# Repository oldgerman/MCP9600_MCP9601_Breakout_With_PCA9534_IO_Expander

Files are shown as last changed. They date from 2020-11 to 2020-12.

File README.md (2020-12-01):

# MCP9600/MCP9601 Breakout, With PCA9534 IO Expander 

- <span style="color:rgb(255, 0, 0);">The module has a bug, don’t make a board.</span>
- <span style="color:rgb(255, 0, 0);">该模块有BUG，不要打板</span>

## PCB

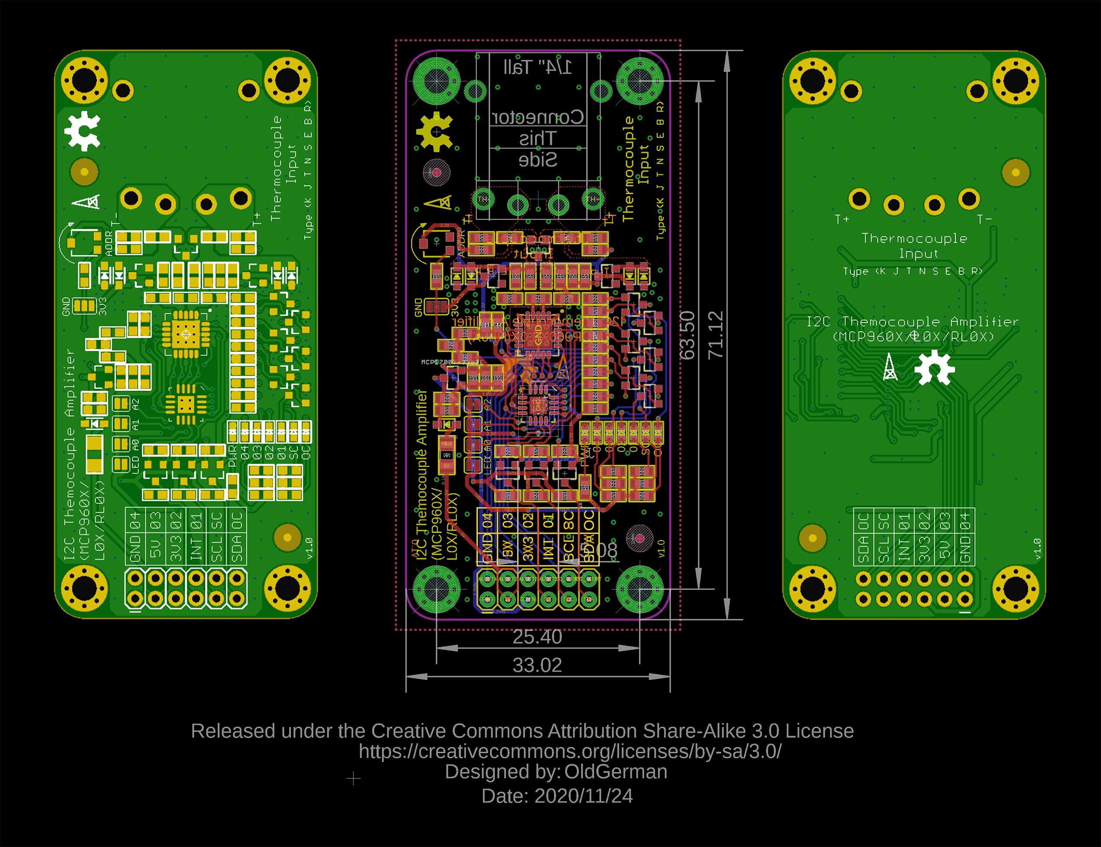
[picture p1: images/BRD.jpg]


## SCH

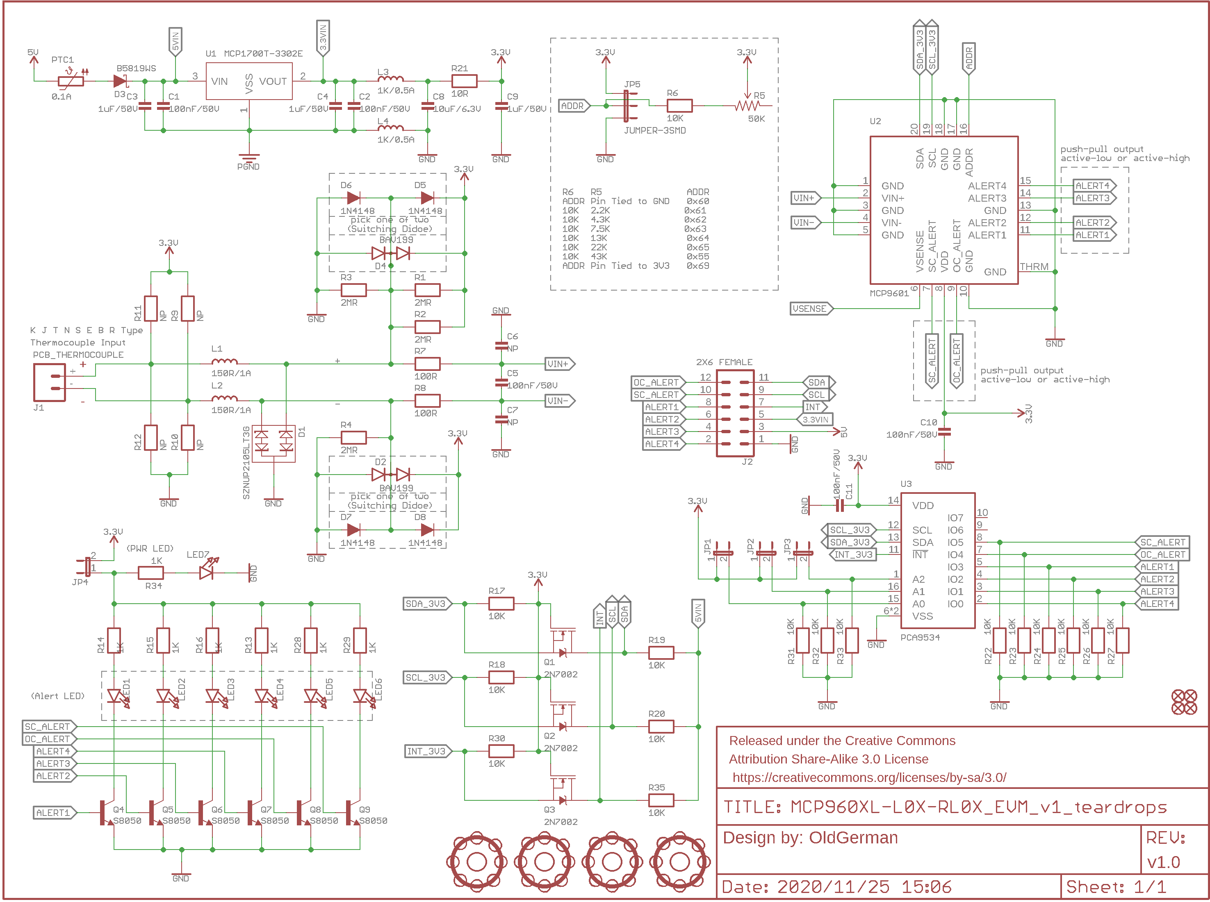
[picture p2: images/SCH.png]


## BOM

Please see bom/ibom.html

## Connectors

1. 5.08mm Pitch 2Pin Plug

2. [OMEGA Circuit Board Thermocouple Connectors](https://www.omega.com/en-us/temperature-measurement/temperature-connectors%2C-panels-and-block-assemblies/temperature-connectors/p/PCC-OST-SMP)

## Pictures

:confused:

## Libraries

1. [PCA9534](https://github.com/alotaiba/PCA9534)
2. [MCP9600](https://github.com/sparkfun/SparkFun_MCP9600_Arduino_Library)

## Reference

1. [Microchip：MCP9600 Evaluation Board](https://www.microchip.com/adm00665-063015a)

2. [Maxim：MAX31855PMB1 Peripheral Module](https://www.maximintegrated.com/en/products/sensors/MAX31855PMB1.html)

3. [Seeed：Grove - I2C Thermocouple Amplifier MCP9600](https://wiki.seeedstudio.com/Grove-I2C_Thermocouple_Amplifier-MCP9600/)

4. [SparkFun：Qwiic Thermocouple Amplifier - MCP9600](https://www.sparkfun.com/products/16294)

5. [Adafruit：MCP9600 I2C Thermocouple Amplifier](https://www.adafruit.com/product/4101)

## Test

MCP96RL01 + T12 irons TYPE-N

| Read Thermocouple(℃) | Read Ambient(℃) | Measurements(mV) | (Ref Junction 0℃) its 90 table for N Type(mV) | (Ref Junction 0℃) its 90 table for N Type(℃) | Read Ambient + its 90 table N Type  (℃) | error(℃) | Hot air gun(W) |
| --- | --- | --- | --- | --- | --- | --- | --- |
| 100 | 24.62 | 2.1 | 2.106 | 78 | 102.62 | 2.62 | 314 |
| 156 | 24.75 | 3.8 | 3.803 | 135 | 159.75 | 3.75 | 500 |
| 180 | 24.56 | 4.6 | 4.618 | 160 | 184.56 | 4.56 | 587 |
| 190 | 25.37 | 4.8 | 4.809 | 167 | 192.37 | 2.37 | 600 |

## Alert 引脚的下拉电阻

MCP9601的6个Alert引脚均为推挽输出，复位后默认状态为Alert1~4输出高电平，OC Alert和SC Alert均使能，高电平表示OC触发，SC触发，或温度警报触发，无PCF9534时，6个Alert引脚不需要下拉电阻，Alert的3.3V高电平可正常输出给MCU

若焊接了PCF9534，则PCF9534复位的寄存器默认值将io 0~7配置为高阻抗输出驱动器的输入，输入电压可以升高到VDD以上，最大为5.5V，此时需要焊接所有Alert pins的下拉电阻，确保Alert的高电平为3.3V

## Important premise of the data sheet

### 3.4 Push-Pull Alert Outputs (Alert 1, 2, 3, 4 and OC/SC Alert)

Alert引脚是用户可编程的推挽输出，可用于检测温度上升或下降。当环境温度超过用户设置的温度警报极限时，设备输出**高电平**信号。 对于MCP9601 / L01 / RL01，当在VSENSE引脚上检测到开路和短路条件时，OC Alert和SC Alert输出才有效，这两个Alerts也是**高电平有效**推挽输出

### 6.3.3.1开路检测技术

mcp9600和mcp9601都具有开路检测技术（即使mcp9600没有V<sub>SENSE</sub>和OC Alert引脚），区别在于mcp9601的OC Alert引脚可以当作硬件指示器

对于MCP9600 / L00 / RL00开路检测，可以使用STATUS寄存器（寄存器5-6）的输入范围位（位4）来检测开路条件。这将需要一些外部电阻，如图6-6所示。无源电路不会影响MCP9600 / L00 / RL00的精度（RB的推荐值设置为1M。连接热电偶时，输入共模电压为 0.5×VDD。当热电偶断开连接，VIN +输入端的电压为 0.66×VDD，VIN-输入端的电压下拉至VSS。此更改将强制设置输入范围位。

MCP9601 / L01 / RL01开路检测机制的工作原理类似（请参见图6-7），检测阈值指定为V<sub>SiOC</sub>和V<sub>SiNOR</sub>（请参见DC特性）。主控制器可以立即轮询状态位以检测开路条件。对于MCP9601 / L01 / RL01，可以将OC Alert引脚用作硬件指示器。

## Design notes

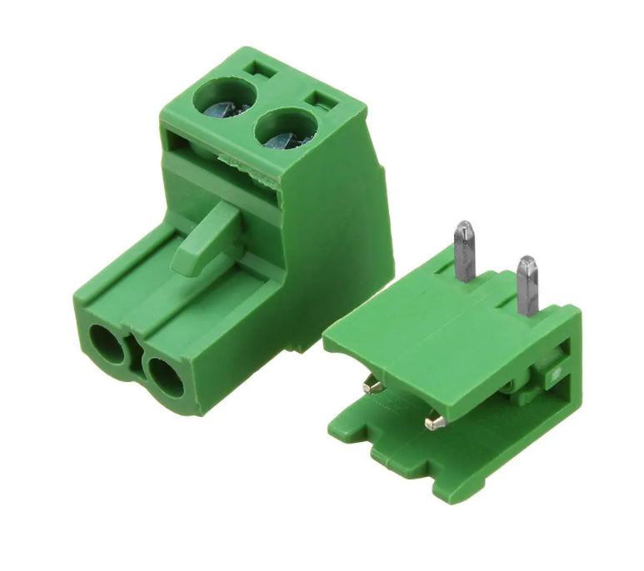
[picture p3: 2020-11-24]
Connectors/5.08mm_Connector(3).png

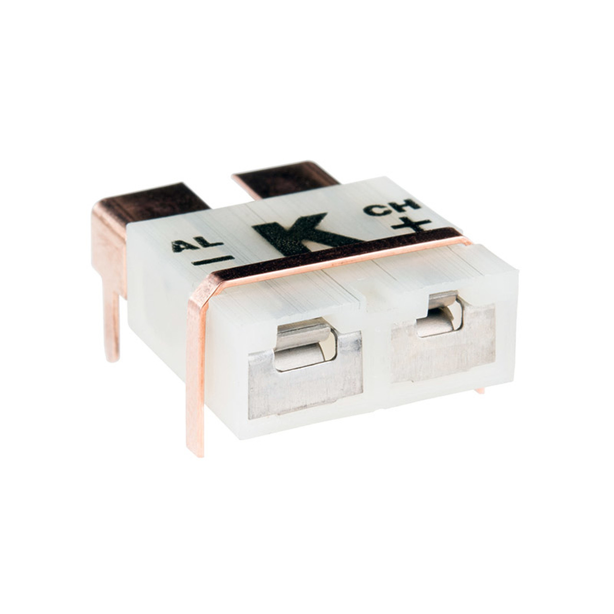
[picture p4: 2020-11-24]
Connectors/Thermocouple_Connector_PCC-SMP-K(2).jpg

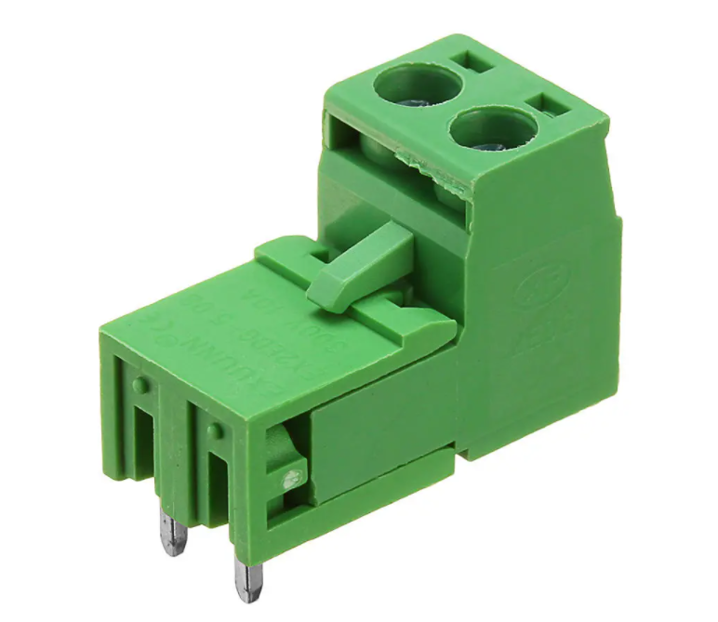
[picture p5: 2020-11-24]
Connectors/5.08mm_Connector(1).png

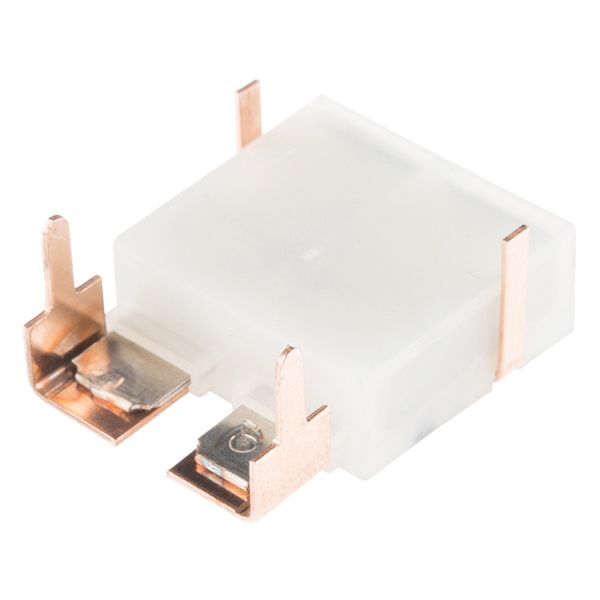
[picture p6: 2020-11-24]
Connectors/Thermocouple_Connector_PCC-SMP-K(1).jpg

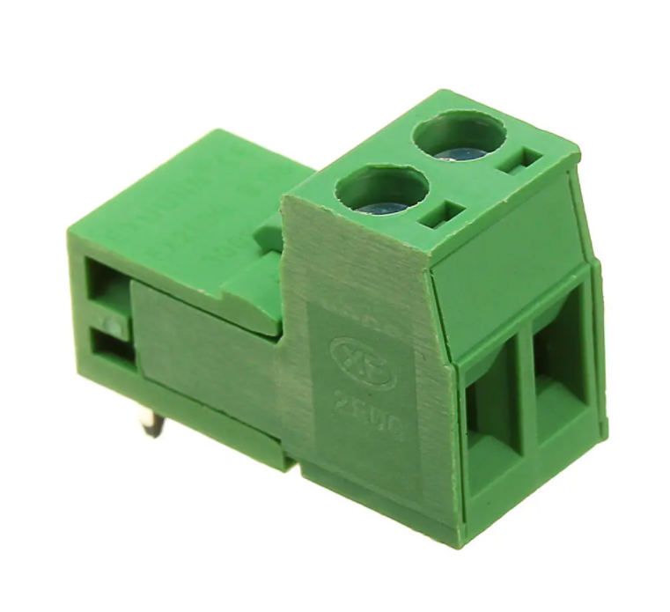
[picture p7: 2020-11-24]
Connectors/5.08mm_Connector(2).png

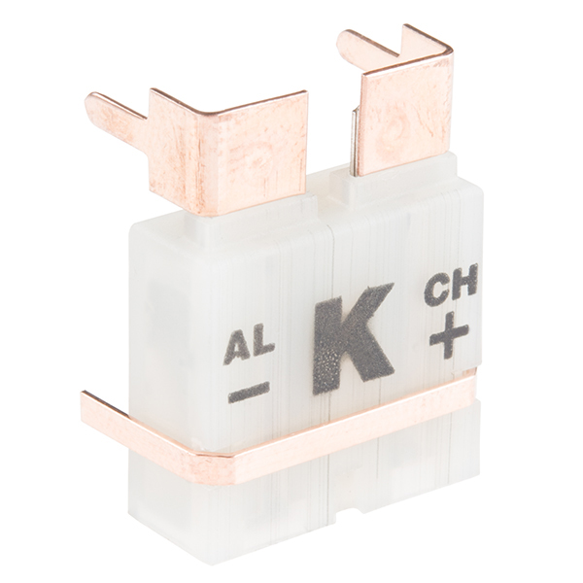
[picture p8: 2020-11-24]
Connectors/Thermocouple_Connector_PCC-SMP-K(3).jpg

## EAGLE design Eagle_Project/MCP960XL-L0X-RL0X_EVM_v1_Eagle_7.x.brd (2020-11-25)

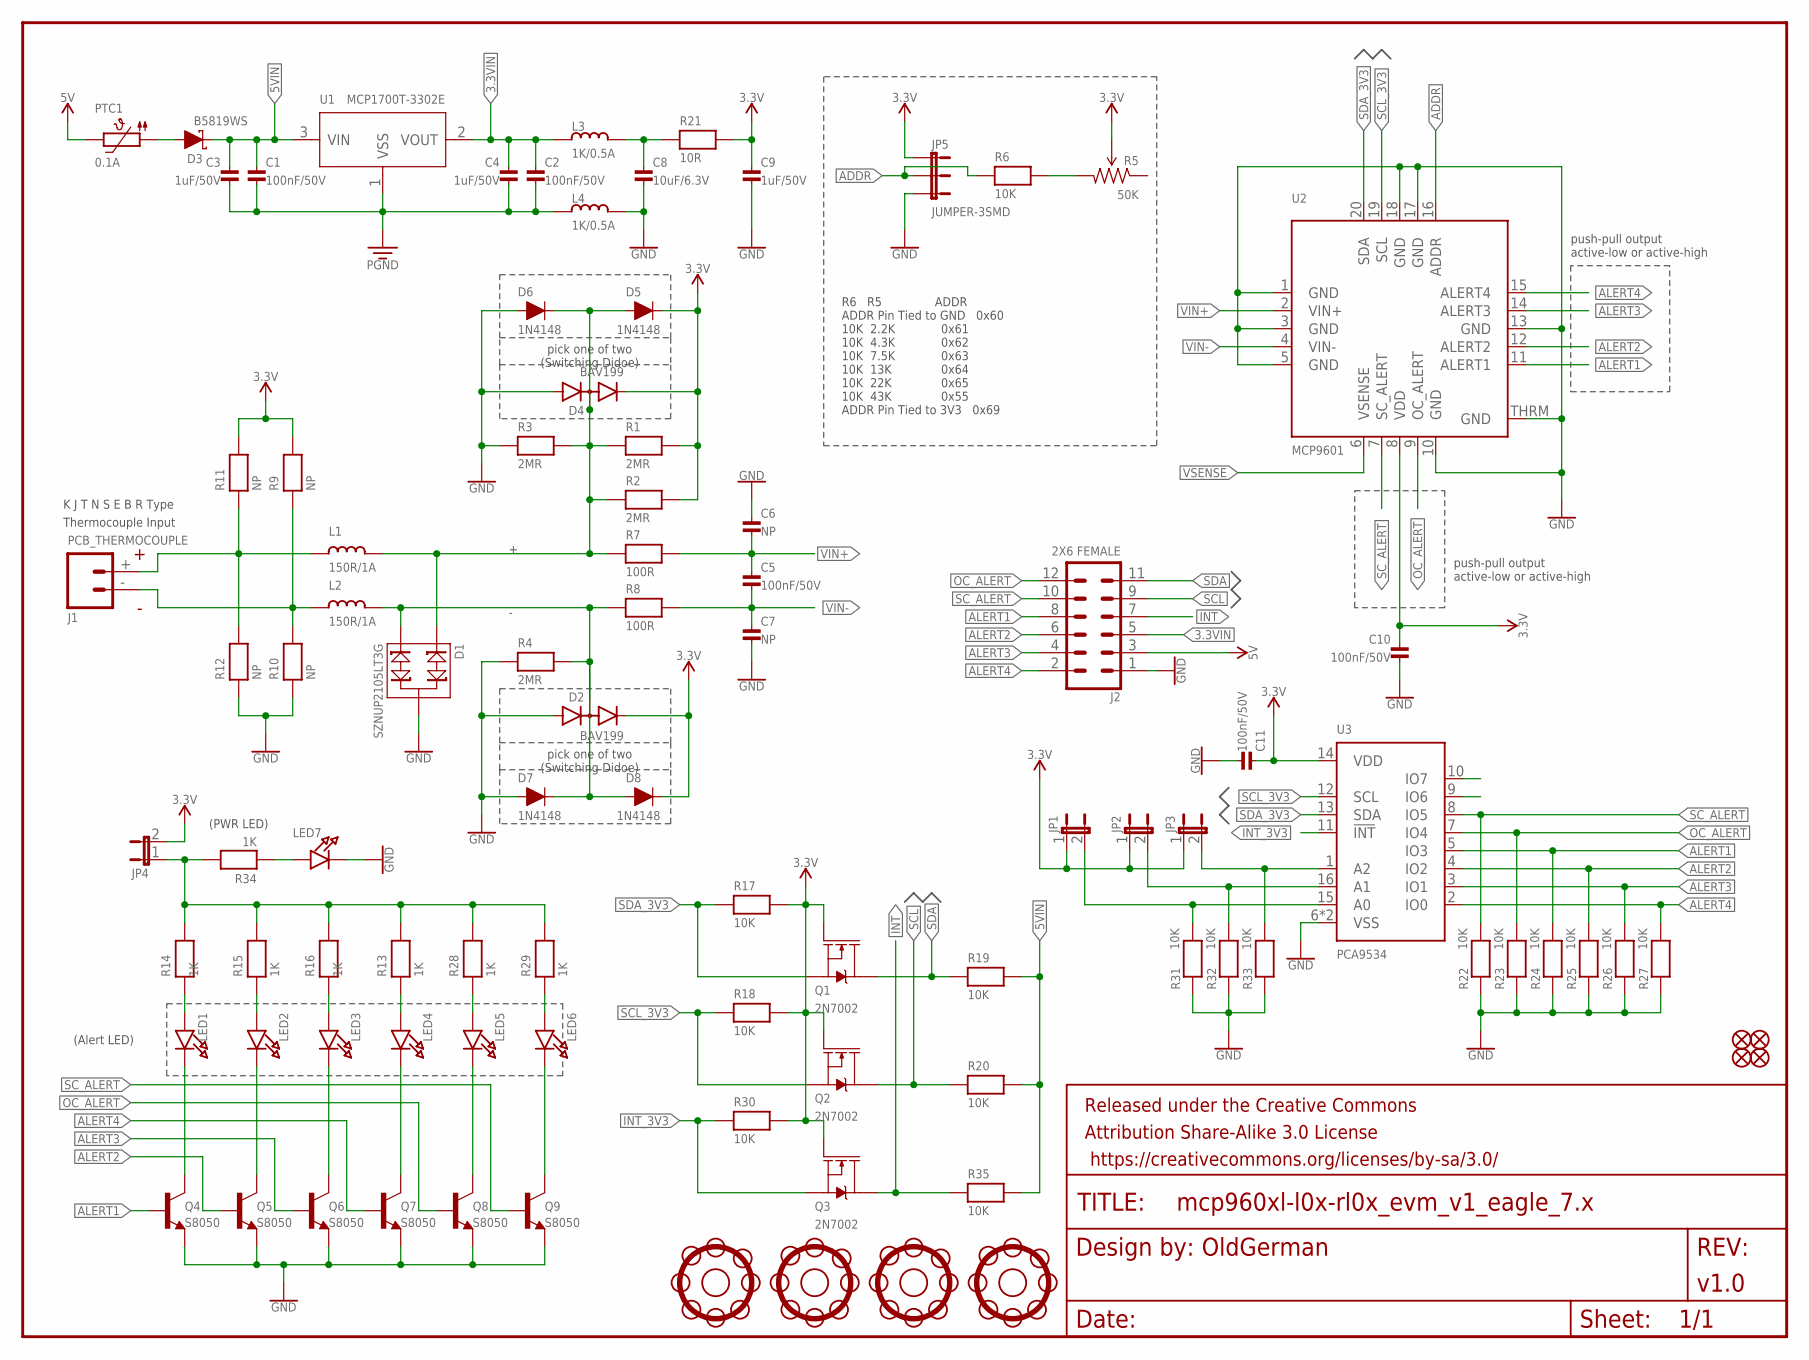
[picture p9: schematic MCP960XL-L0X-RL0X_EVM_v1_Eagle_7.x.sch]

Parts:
C1, C2, C5, C10, C11: 100nF/50V; 0603
C3, C4, C9: 1uF/50V; 0603
C6, C7: NP; 0603
C8: 10uF/6.3V; 0603
D1: SZNUP2105LT3G; SOT23-3
D2, D4: BAV199; SOT23-3
D3: B5819WS; SOD-323
D5, D6, D7, D8: 1N4148; SOD-323
FID1, FID2, FID3, FID4: FIDUCIAL1X2.5; FIDUCIAL-1X2.5
FRAME1: FRAME-LETTER; CREATIVE_COMMONS
J1: PCB_THERMOCOUPLE; PCC-SMP
J2: 2X6 FEMALE; 2X6
JP1, JP2, JP3, JP4: JUMPER-2SMD-NC; SJ_2S
JP5: JUMPER-3SMD; SJ_3
L1, L2: 150R/1A; 0603
L3, L4: 1K/0.5A; 0603
LED1, LED2, LED3, LED4, LED5, LED6, LED7: LED0603; CHIPLED_0603
PTC1: 0.1A; 1206
Q1, Q2, Q3: 2N7002; SOT23-3
Q4, Q5, Q6, Q7, Q8, Q9: S8050; SOT23-3
R1, R2, R3, R4: 2MR; 0603
R5: 50K; TRIMPOT-3MM
R6, R17, R18, R19, R20, R22, R23, R24, R25, R26, R27, R30, R31, R32, R33, R35: 10K; 0603
R7, R8: 100R; 0603
R9, R10, R11, R12: NP; 0603
R13, R14, R15, R16, R28, R29, R34: 1K; 0603
R21: 10R; 0603
U1: MCP1700T-3302E; SOT23-3
U2: MCP9601; VQFN20_5MM
U3: PCA9534; HVQFN16_4X4_0.65MM
U$1, U$3, U$4, U$6: SUN_HOLE_M3

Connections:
3.3V: C9.1, C10.1, C11.1, D2.3 (C), D4.3 (C), D5.C, D8.C, JP1.1, JP2.1, JP3.1, JP4.2, JP5.1, Q1.1 (G), Q2.1 (G), Q3.1 (G), R1.2, R2.2, R5.2 (WIPER), R9.2, R11.2, R17.2, R18.2, R21.2, R30.2, U2.8 (VDD), U3.14 (VDD)
3.3VIN: C2.1, C4.1, J2.5, L3.1, U1.2 (VOUT)
5V: J2.3, PTC1.2
5VIN: C1.1, C3.1, D3.C, R19.2, R20.2, R35.2, U1.3 (VIN)
A0: JP1.2, R31.2, U3.15 (A0)
A1: JP2.2, R32.2, U3.16 (A1)
A2: JP3.2, R33.2, U3.1 (A2)
ADDR: JP5.2, R6.1, U2.16 (ADDR)
ALERT1: J2.8, Q4.1 (B), R24.2, U2.11 (ALERT1), U3.5 (IO3)
ALERT2: J2.6, Q5.1 (B), R25.2, U2.12 (ALERT2), U3.4 (IO2)
ALERT3: J2.4, Q6.1 (B), R26.2, U2.14 (ALERT3), U3.3 (IO1)
ALERT4: J2.2, Q7.1 (B), R27.2, U2.15 (ALERT4), U3.2 (IO0)
GND: C6.1, C7.2, C8.2, C9.2, C10.2, C11.2, D1.3, D2.1 (A), D4.1 (A), D6.A, D7.A, J2.1, JP5.3, L4.2, LED7.C, Q4.2 (E), Q5.2 (E), Q6.2 (E), Q7.2 (E), Q8.2 (E), Q9.2 (E), R3.1, R4.1, R10.1, R12.1, R22.1, R23.1, R24.1, R25.1, R26.1, R27.1, R31.1, R32.1, R33.1, U2.1 (GND), U2.3 (GND), U2.5 (GND), U2.10 (GND), U2.13 (GND), U2.17 (GND), U2.18 (GND), U2.THRM (GND), U3.6 (VSS), U3.PAD (VSS)
INT: J2.7, Q3.3 (D), R35.1
INT_3V3: Q3.2 (S), R30.1, U3.11 (!INT)
L1_OUT: D1.1, D4.2 (AC), D5.A, D6.C, L1.2, R1.1, R2.1, R3.2, R7.1
L2_OUT: D1.2, D2.2 (AC), D7.C, D8.A, L2.2, R4.2, R8.1
unnamed: R5.1 (CW), R6.2
unnamed: C8.1, L3.2, R21.1
unnamed: LED4.C, Q7.3 (C)
unnamed: LED4.A, R13.1
unnamed: LED7.A, R34.1
unnamed: LED5.C, Q8.3 (C)
unnamed: LED1.C, Q4.3 (C)
unnamed: LED5.A, R28.1
unnamed: LED6.C, Q9.3 (C)
unnamed: LED1.A, R14.1
unnamed: LED2.C, Q5.3 (C)
unnamed: LED2.A, R15.1
unnamed: LED3.C, Q6.3 (C)
unnamed: LED3.A, R16.1
unnamed: LED6.A, R29.1
unnamed: D3.A, PTC1.1
unnamed: JP4.1, R13.2, R14.2, R15.2, R16.2, R28.2, R29.2, R34.2
OC_ALERT: J2.12, Q8.1 (B), R23.2, U2.9 (OC_ALERT), U3.7 (IO4)
PGND: C1.2, C2.2, C3.2, C4.2, L4.1, U1.1 (VSS)
SCL: J2.9, Q2.3 (D), R20.1
SCL_3V3: Q2.2 (S), R18.1, U2.19 (SCL), U3.12 (SCL)
SC_ALERT: J2.10, Q9.1 (B), R22.2, U2.7 (SC_ALERT), U3.8 (IO5)
SDA: J2.11, Q1.3 (D), R19.1
SDA_3V3: Q1.2 (S), R17.1, U2.20 (SDA), U3.13 (SDA)
TH+: J1.+, L1.1, R11.1, R12.2
TH-: J1.-, L2.1, R9.1, R10.2
VIN+: C5.1, C6.2, R7.2, U2.2 (VIN+)
VIN-: C5.2, C7.1, R8.2, U2.4 (VIN-)
VSENSE: U2.6 (VSENSE)

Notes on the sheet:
Thermocouple Input
K J T N S E B R Type
push-pull output active-low or active-high
pick one of two (Switching Didoe)
(PWR LED)
(Alert LED)
R6 R5 ADDR ADDR Pin Tied to GND 0x60 10K 2.2K 0x61 10K 4.3K 0x62 10K 7.5K 0x63 10K 13K 0x64 10K 22K 0x65 10K 43K 0x55 ADDR Pin Tied to 3V3 0x69
OldGerman
v1.0

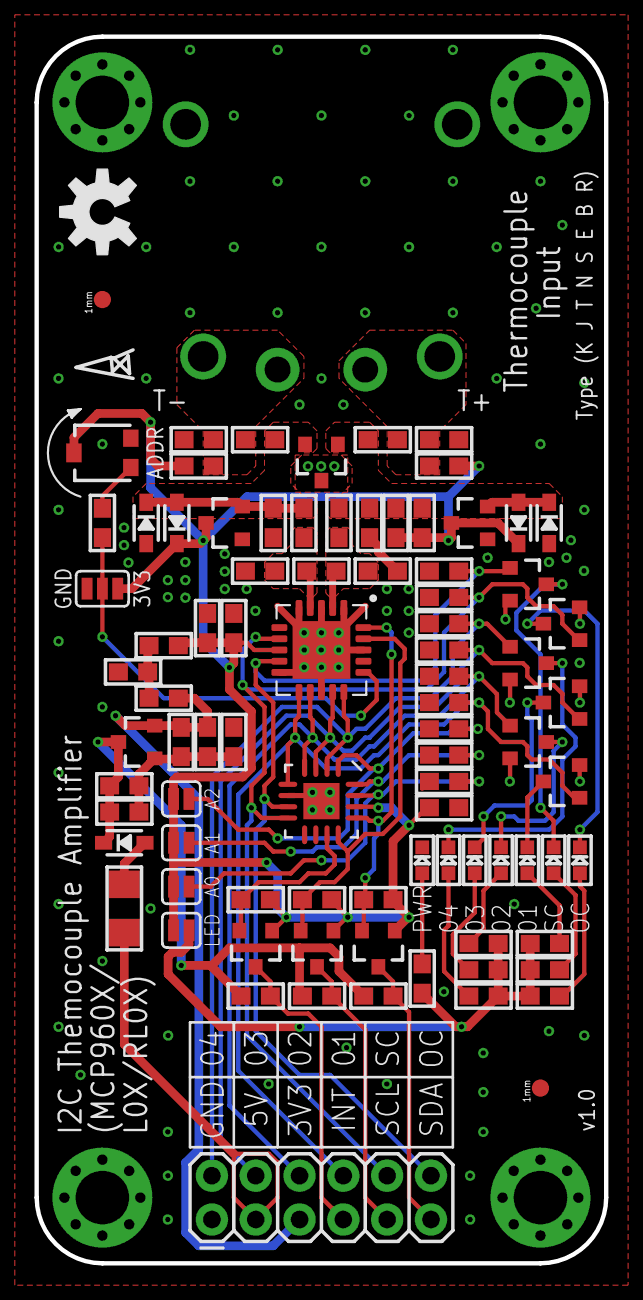
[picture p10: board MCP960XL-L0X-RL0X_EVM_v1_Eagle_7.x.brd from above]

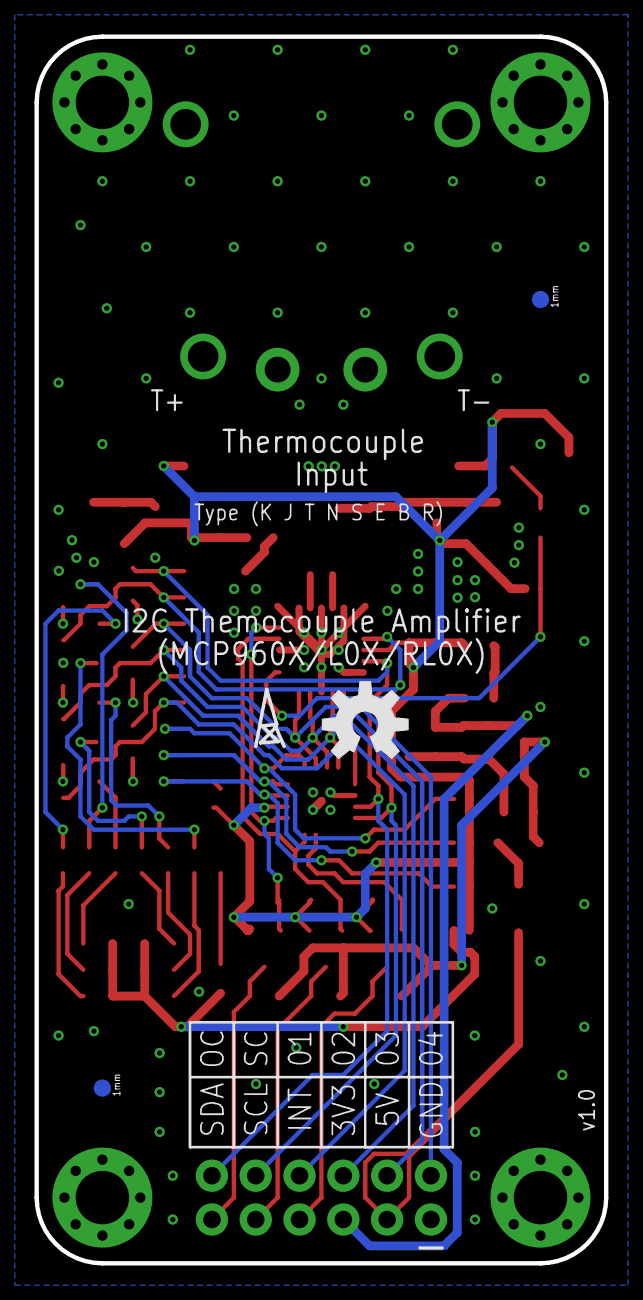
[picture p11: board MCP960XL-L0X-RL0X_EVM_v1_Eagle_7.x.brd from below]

Board: 2 copper layers, 33.0 x 71.1 mm, 96 parts (4 on the bottom side), 45 nets.

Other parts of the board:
U$2, U$5: OSHW-LOGO-M

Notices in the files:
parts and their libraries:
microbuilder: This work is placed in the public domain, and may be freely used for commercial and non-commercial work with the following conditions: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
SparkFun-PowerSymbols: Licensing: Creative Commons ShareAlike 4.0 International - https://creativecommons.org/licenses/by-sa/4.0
